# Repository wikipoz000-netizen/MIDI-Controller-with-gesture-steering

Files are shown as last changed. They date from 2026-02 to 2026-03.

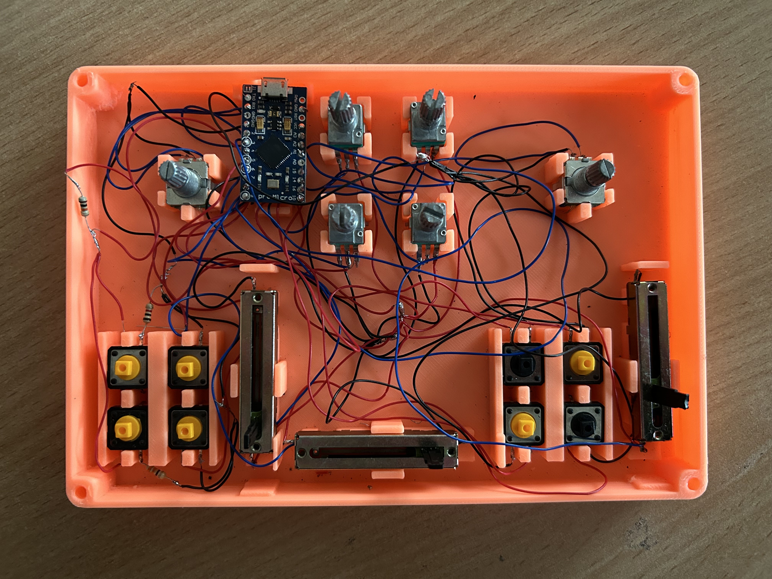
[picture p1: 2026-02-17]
pictures./budowa_DIY.jpg

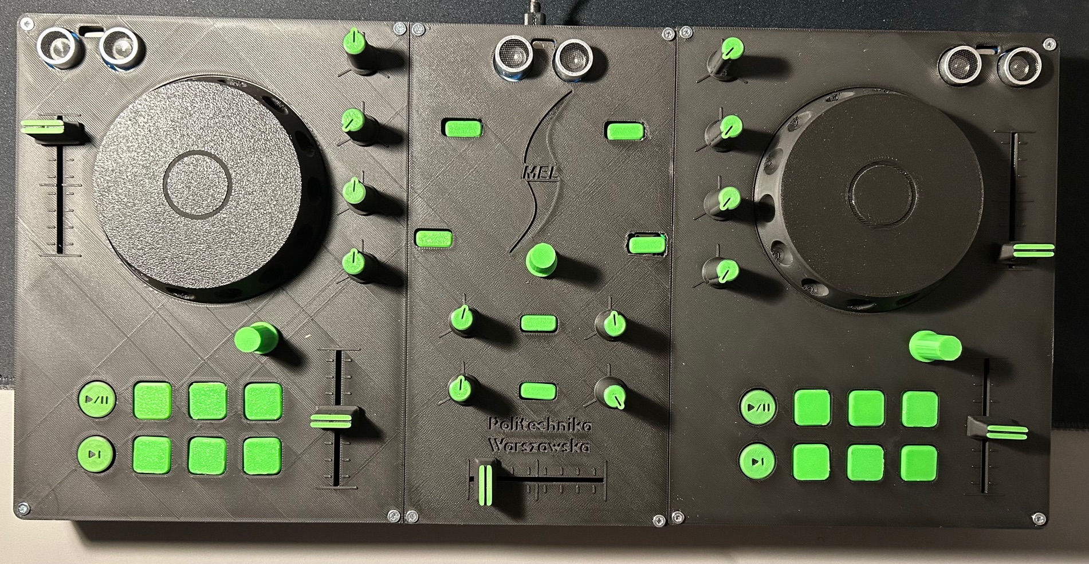
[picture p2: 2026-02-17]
pictures./final.jpeg

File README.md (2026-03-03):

English below
# MIDI DJ Controller z kontrolą gestami

Projekt przedstawia autorski kontroler MIDI DJ wzbogacony o eksperymentalny system sterowania gestami. Urządzenie zostało opracowane w ramach pracy inżynierskiej na kierunku **Automatyka i Robotyka**.

## Opis projektu

Urządzenie łączy tradycyjne elementy kontrolera DJ (fadery, pokrętła, koła jog, przyciski) z warstwą bezdotykowego sterowania gestami opartą na ultradźwiękowych czujnikach odległości.

Kontroler komunikuje się z komputerem poprzez interfejs **USB-MIDI** i jest w pełni kompatybilny z oprogramowaniem DJ-skim, takim jak **Mixxx**.

## Sprzęt (Hardware)

Główne komponenty systemu:

* **Mikrokontroler:** Raspberry Pi Pico (RP2040)
* **Wejścia analogowe:** Multiplekser ADC (rozszerzenie liczby kanałów analogowych)
* **Wejścia cyfrowe:** Ekspander GPIO (dodatkowe wejścia dla przycisków)
* **Detekcja gestów:** Ultradźwiękowe czujniki odległości
* **Interfejs dotykowy:** Pojemnościowe czujniki dotyku
* **Konstrukcja:** Dedykowana płytka PCB oraz obudowa wykonana w technologii druku 3D

Pełna dokumentacja sprzętowa, schematy oraz projekty PCB znajdują się w katalogu `/hardware`.

## Oprogramowanie układowe (Firmware)

Firmware odpowiada za:

* Odczyt i filtrowanie sygnałów z wejść analogowych i cyfrowych.
* Skalowanie sygnałów i eliminację szumów.
* Interpretację danych z czujników na konkretne gesty.
* Generowanie komunikatów MIDI (**Note On/Off, Control Change, Pitch Bend**).
* Komunikację USB-MIDI o niskim opóźnieniu.

Kod źródłowy dostępny jest w katalogu `/firmware`.

## Integracja z oprogramowaniem

Kontroler został przetestowany z oprogramowaniem **Mixxx**. W repozytorium znajdują się niezbędne pliki mapowania MIDI (formaty `.xml` oraz `.js`).

## Zawartość repozytorium

* **Hardware:** Schematy ideowe i projekty płytek drukowanych.
* **Firmware:** Kod źródłowy mikrokontrolera.
* **Mapping:** Pliki konfiguracyjne MIDI dla oprogramowania DJ.
* **Dokumentacja:** Wyniki testów i specyfikacja techniczna.

---

# MIDI DJ Controller with Gesture Control

This project presents a custom-built MIDI DJ controller enhanced with an experimental gesture control system.  
It was developed as part of an engineering thesis in Robotics and Automation.

## Project Description

The device combines traditional DJ controller elements (faders, knobs, jog wheels, buttons) with a contactless gesture control layer based on ultrasonic distance sensors.

The controller communicates with a computer via USB-MIDI and is compatible with DJ software such as Mixxx.

## Hardware

Main components:

- Raspberry Pi Pico (RP2040)
- ADC multiplexer (for extended analog inputs)
- GPIO expander (for additional digital inputs)
- Ultrasonic distance sensors (gesture detection)
- Capacitive touch sensing
- Custom-designed PCB
- 3D-printed enclosure

All hardware schematics and PCB files are available in the `/hardware` directory.

## Firmware

The firmware is responsible for:

- Reading analog and digital inputs
- Signal filtering and scaling
- Gesture interpretation
- Generating MIDI messages (Note On/Off, Control Change, Pitch Bend)
- USB-MIDI communication

Source code is available in the `/firmware` directory.

## Software Integration

The controller was tested with Mixxx DJ software.  
The repository includes MIDI mapping files (XML and JS).

## Repository Contents

- Hardware schematics
- PCB design files
- Firmware source code
- MIDI mapping configuration
- Documentation and test results

---
## Licencja

Ten projekt jest udostępniony na licencji **Creative Commons Zero**. 
Więcej informacji w pliku [LICENSE](LICENSE).

## Autor

Wiktor Pozarzycki  
Praca inżynierska – 2026

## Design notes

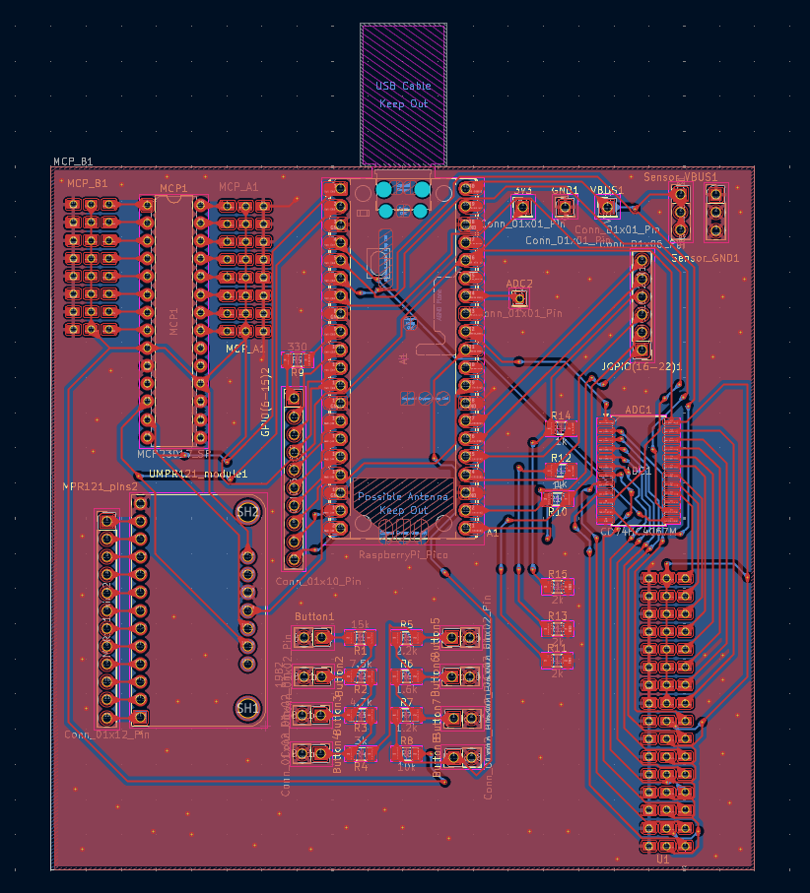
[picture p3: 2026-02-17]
pictures./PCB.png

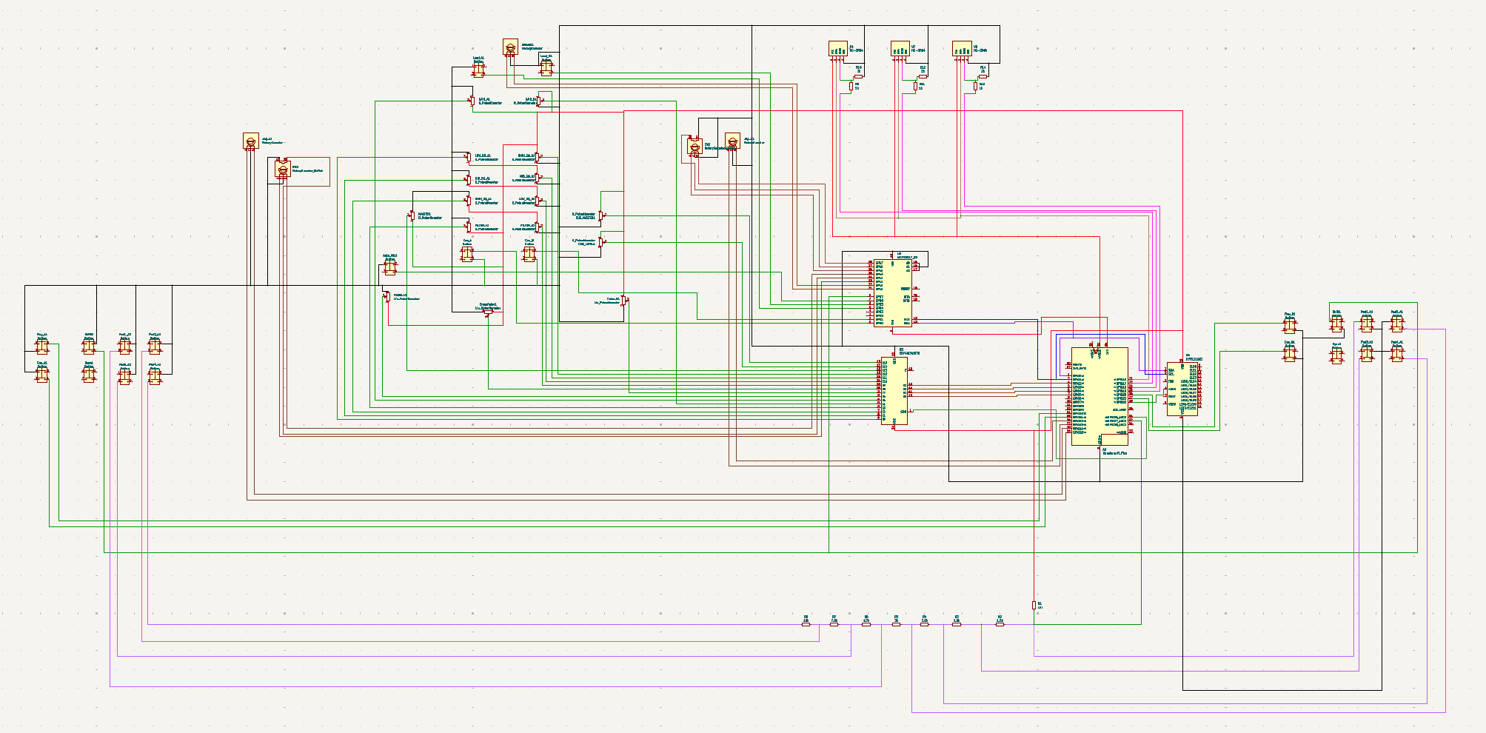
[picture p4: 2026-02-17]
pictures./caly_schemat.png

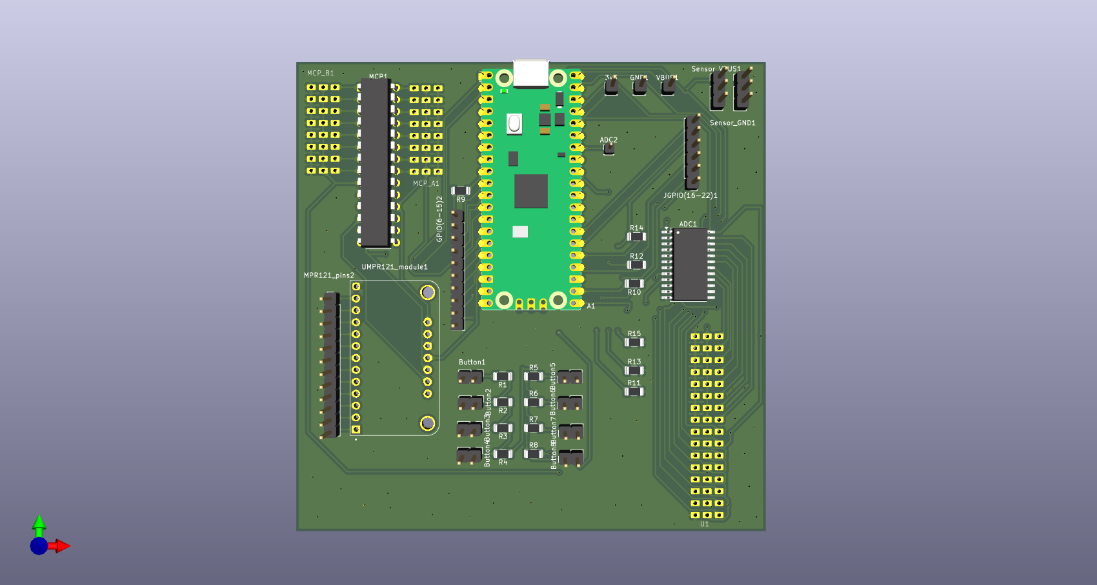
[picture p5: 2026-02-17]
pictures./Schemat_PCB.png

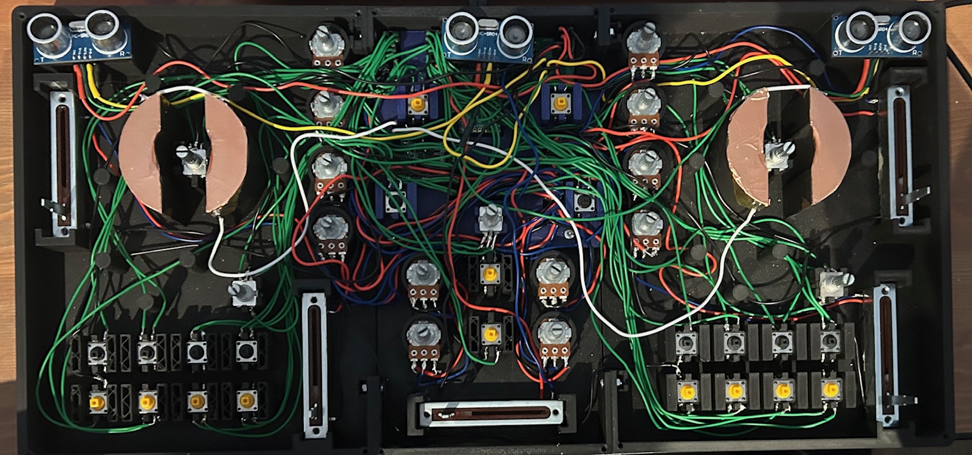
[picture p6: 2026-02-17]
pictures./urzadzenie.jpeg

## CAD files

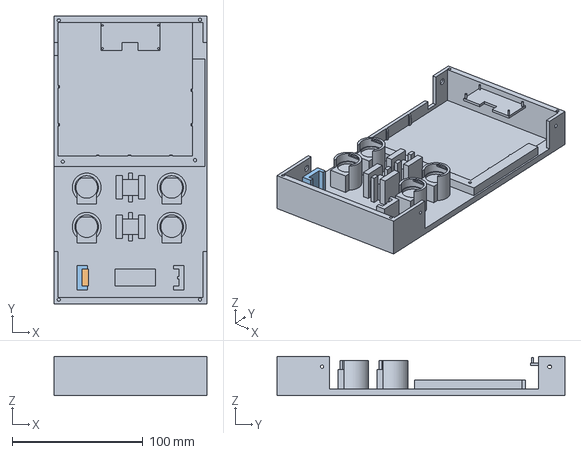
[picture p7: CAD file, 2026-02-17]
3D models/Obudowa_S.step
117.0 x 220.0 x 30.0 mm

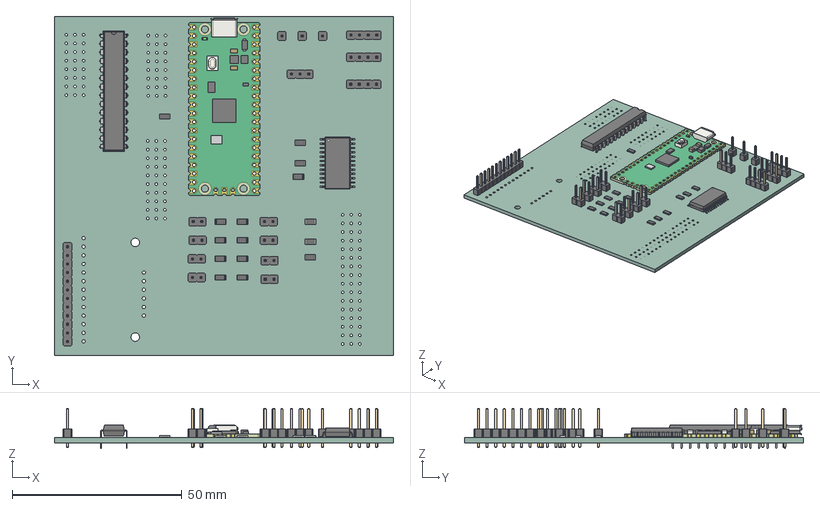
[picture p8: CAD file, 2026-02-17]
schemes/Schemat_PCB/Schemat_PCB.step
100.0 x 100.0 x 11.8 mm
DIP-28_W7.62mm
R_1206_3216Metric x 15
SOIC-24W_7.5x15.4mm_P1.27mm
RaspberryPi_Pico_Module_KiCad
PinHeader_1x02_P2.54mm_Vertical x 8
PinHeader_1x01_P2.54mm_Vertical x 3
PinHeader_1x04_P2.54mm_Vertical x 3
PinHeader_1x12_P2.54mm_Vertical
PinHeader_1x03_P2.54mm_Vertical
Schemat_PCB_PCB

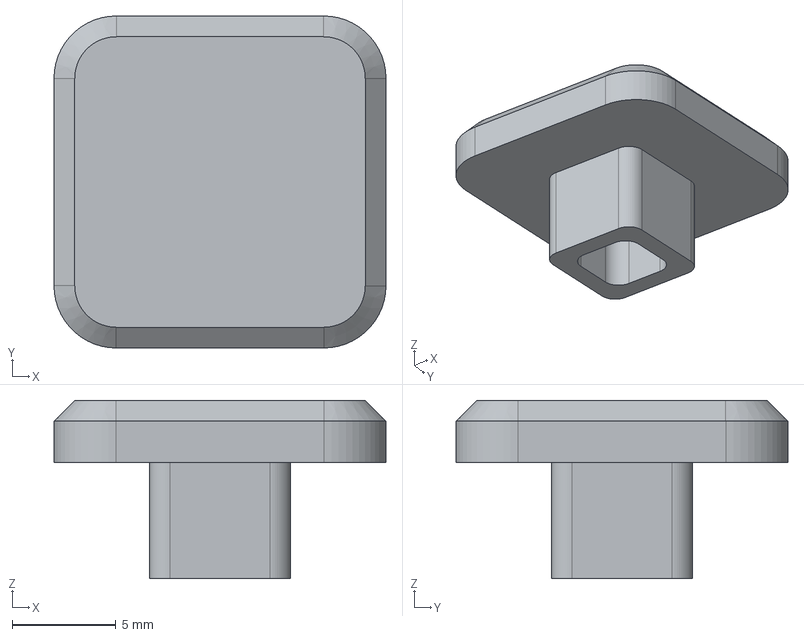
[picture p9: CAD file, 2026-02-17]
3D models/Przycisk_Duzy.step
16.0 x 16.0 x 8.60 mm

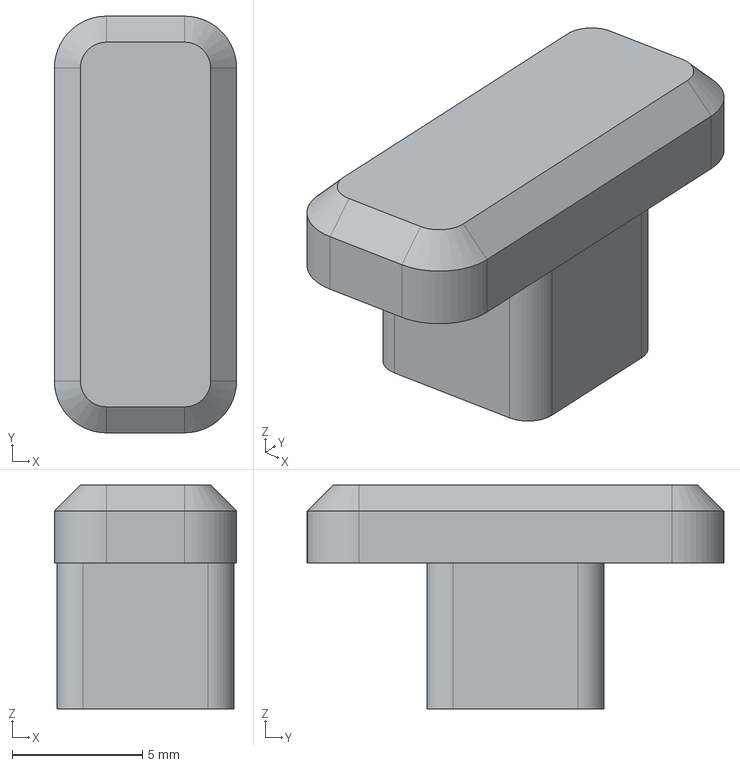
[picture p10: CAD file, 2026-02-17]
3D models/Przycisk_Maly.step
7.00 x 16.0 x 8.60 mm

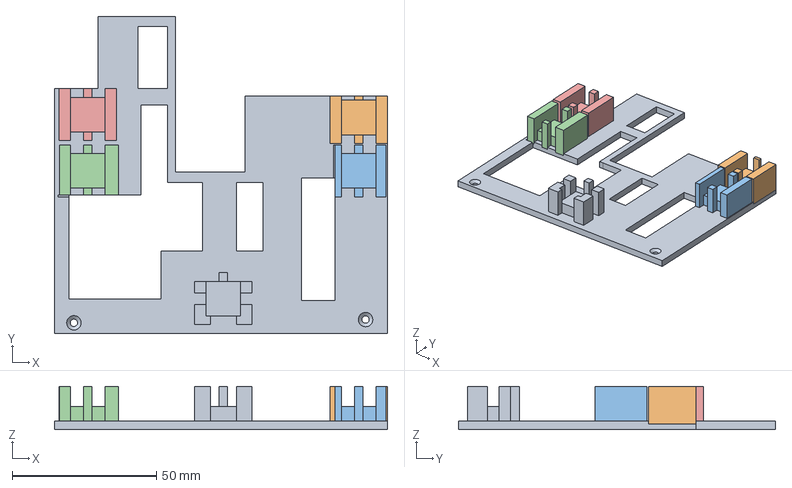
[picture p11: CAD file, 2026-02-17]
3D models/Nakladka2.step
115.5 x 110.0 x 15.0 mm

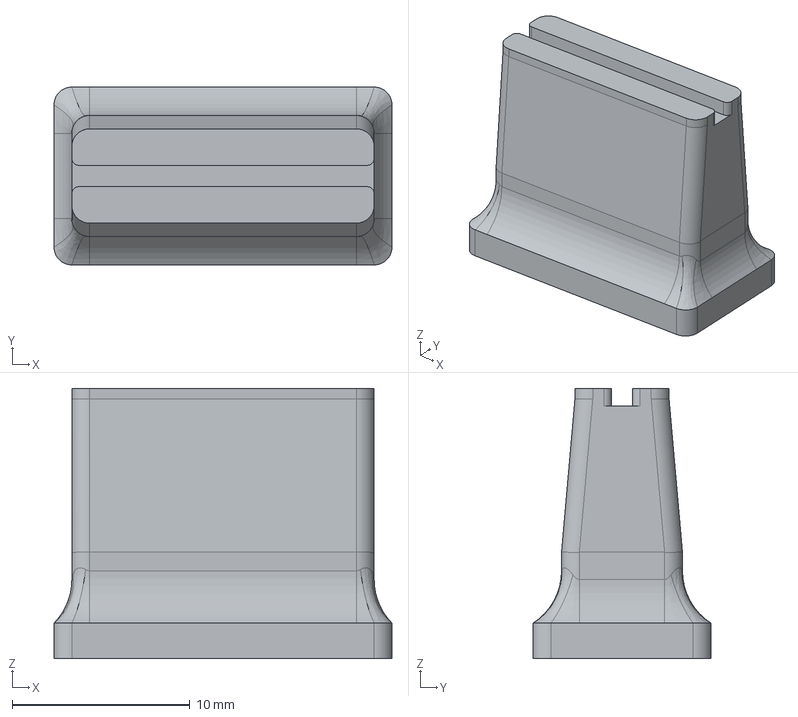
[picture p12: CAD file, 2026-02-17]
3D models/tempo-fader-Body.step
19.0 x 10.0 x 15.2 mm

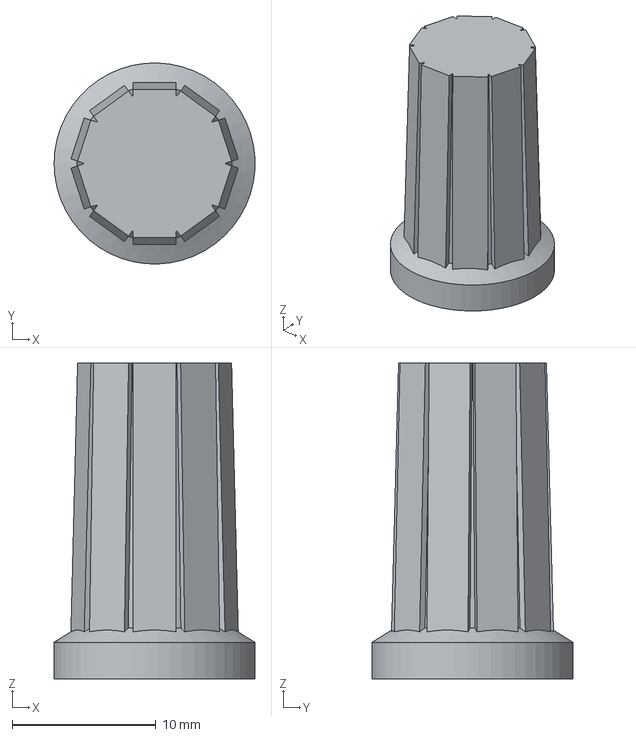
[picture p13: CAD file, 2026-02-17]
3D models/Pokretlo1.step
14.0 x 14.0 x 22.0 mm

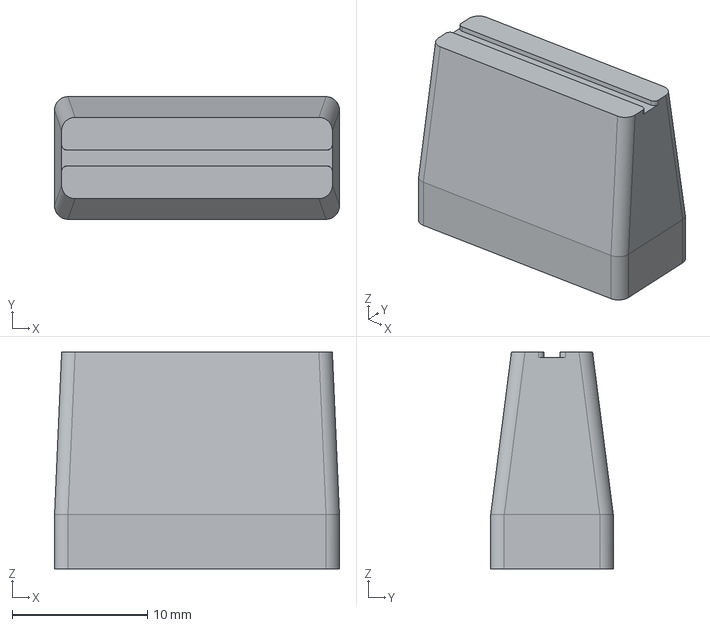
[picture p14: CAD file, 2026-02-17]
3D models/crossfader-BodyFillet.step
21.0 x 9.06 x 16.0 mm

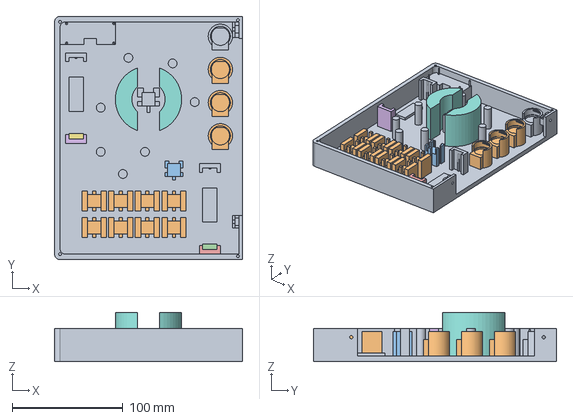
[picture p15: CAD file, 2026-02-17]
3D models/Obudowa_L.step
170.0 x 220.0 x 44.5 mm

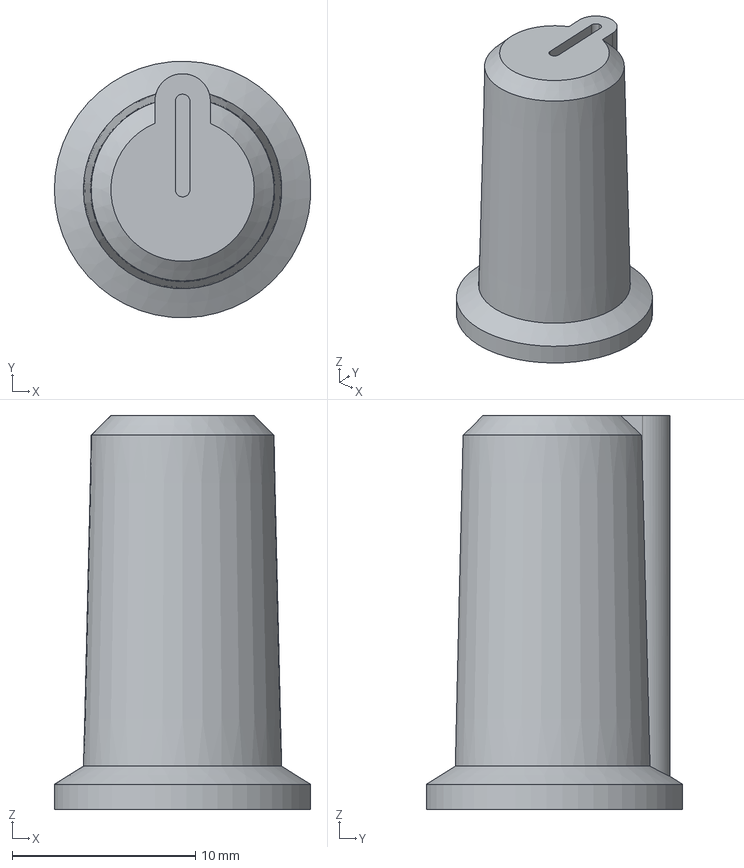
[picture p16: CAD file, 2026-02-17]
3D models/Pokretlo2.step
14.0 x 14.0 x 21.5 mm

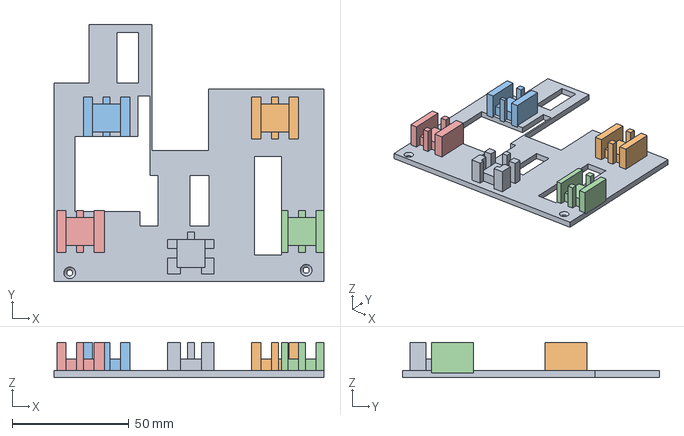
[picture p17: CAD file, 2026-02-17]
3D models/Nakladka.step
115.5 x 110.0 x 15.0 mm

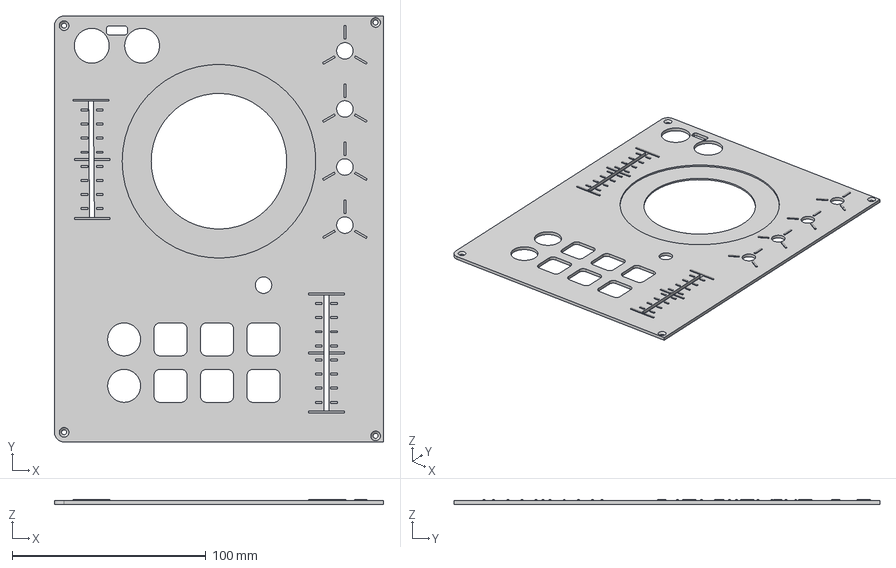
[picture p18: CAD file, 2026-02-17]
3D models/Gora_L.step
170.0 x 220.0 x 2.50 mm

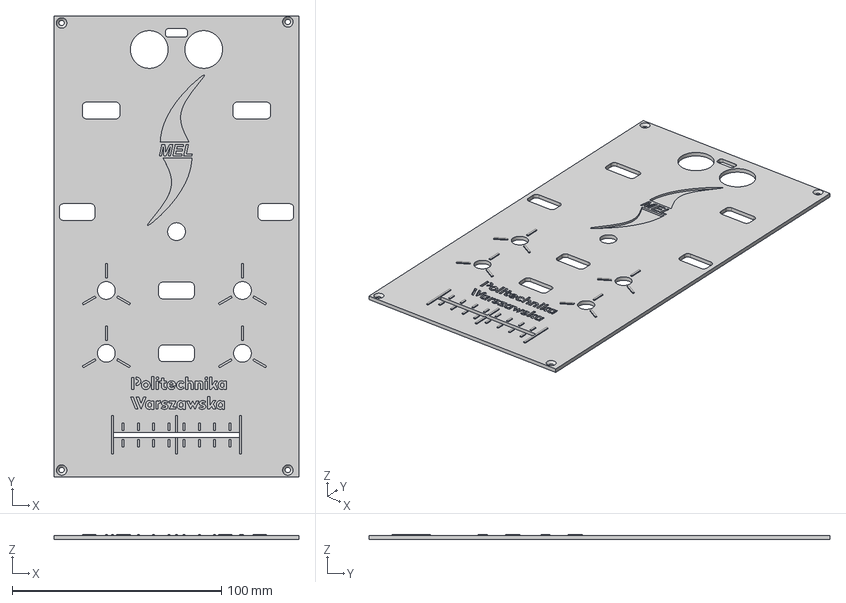
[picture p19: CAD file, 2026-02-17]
3D models/Gora_S.step
117.0 x 220.0 x 2.50 mm

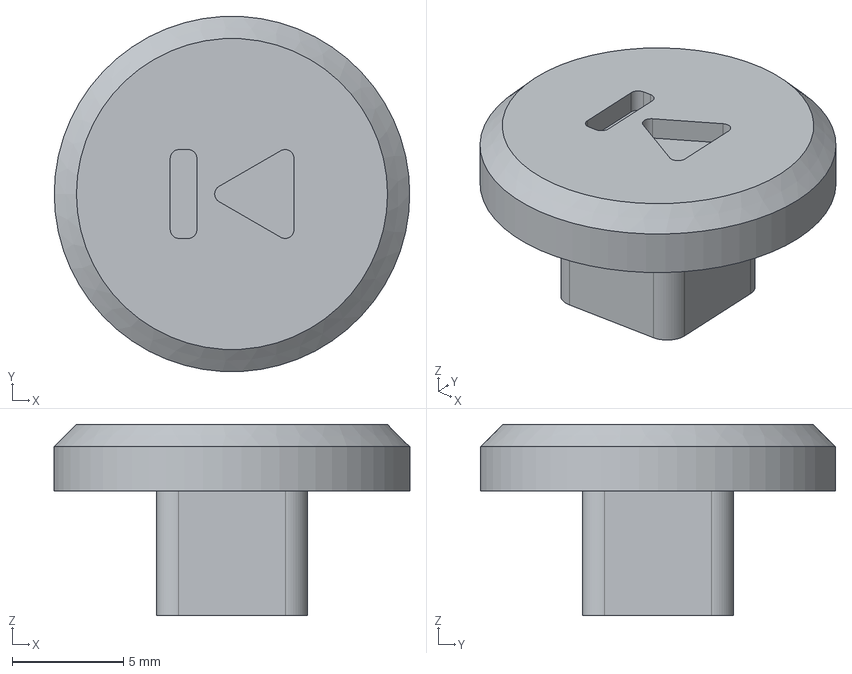
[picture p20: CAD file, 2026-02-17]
3D models/cue-Body.step
16.0 x 16.0 x 8.60 mm

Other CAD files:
3D models/Gora_P.step
3D models/Jog.step
3D models/play-pause-Body.step
3D models/Obudowa_P.step

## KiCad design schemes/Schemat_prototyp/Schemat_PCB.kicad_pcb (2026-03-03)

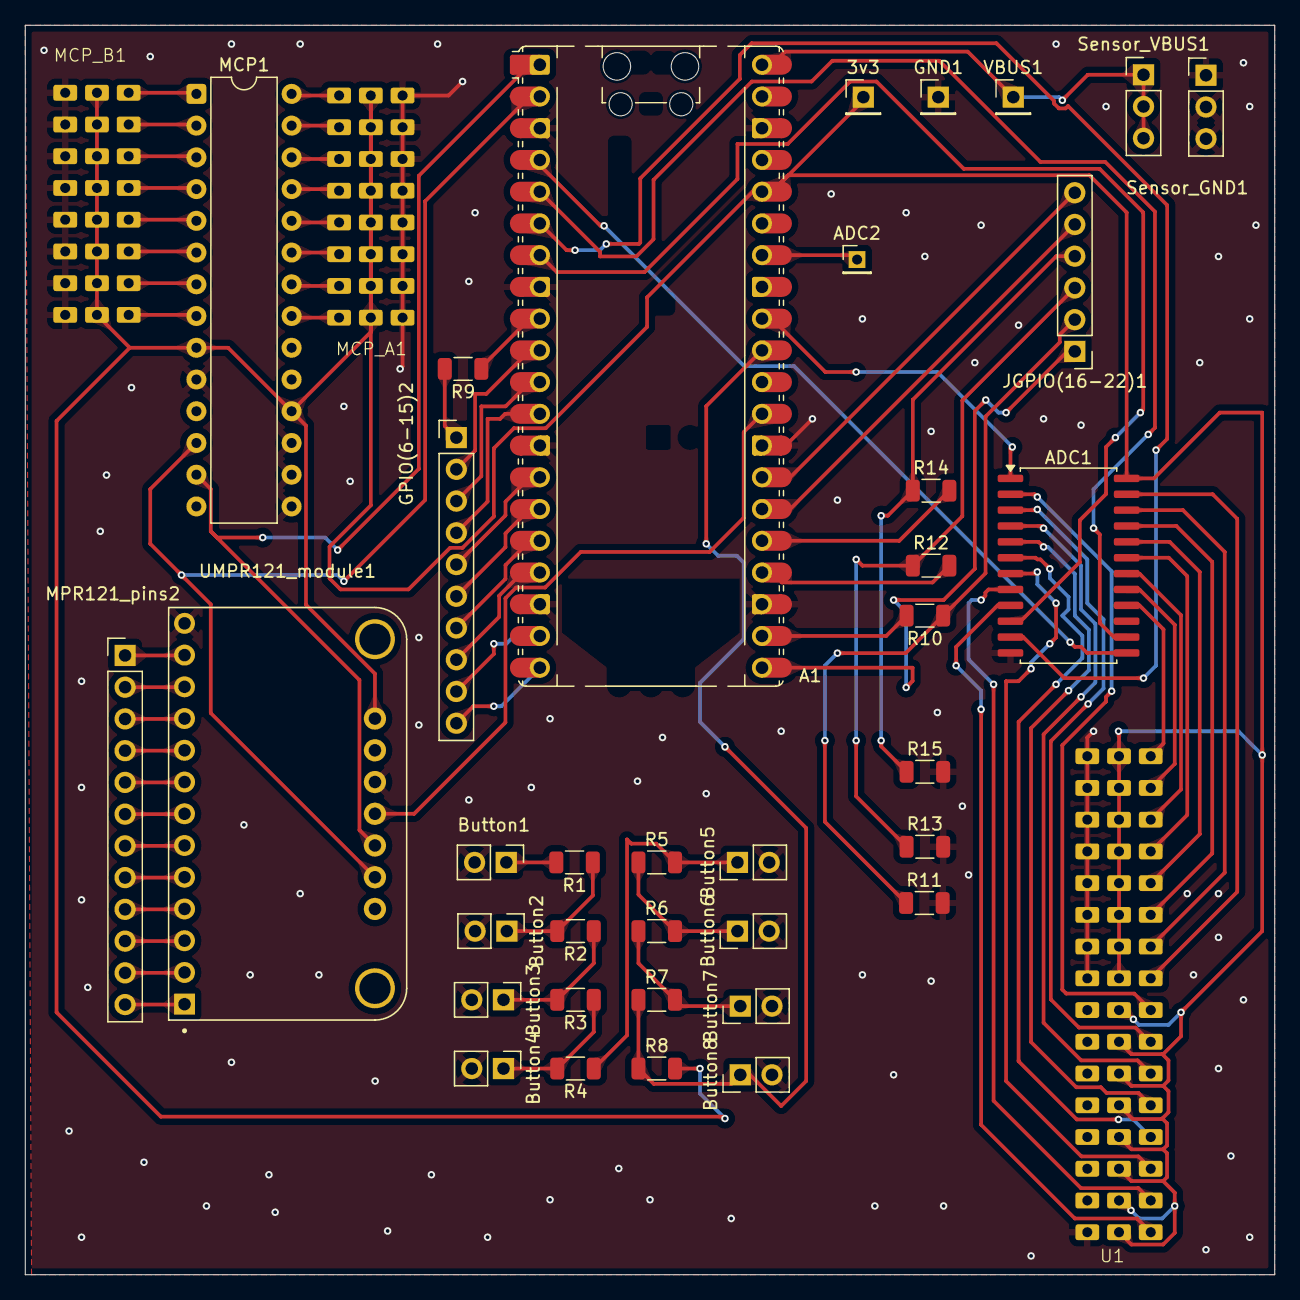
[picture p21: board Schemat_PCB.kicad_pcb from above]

Board: 2 copper layers, 100.0 x 100.0 mm, 39 parts (0 on the bottom side), 84 nets.

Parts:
3v3: Conn_01x01_Pin; PinHeader_1x01_P2.54mm_Vertical
A1: RaspberryPi_Pico; RaspberryPi_Pico_Common_Unspecified
ADC1: CD74HC4067M; SOIC-24W_7.5x15.4mm_P1.27mm
ADC2: Conn_01x01_Pin; PinHeader_1x01_P2.00mm_Vertical
Button1, Button2, Button3, Button4, Button5, Button6, Button7, Button8: Conn_01x02_Pin; PinHeader_1x02_P2.54mm_Vertical
GND1: Conn_01x01_Pin; PinHeader_1x01_P2.54mm_Vertical
GPIO(6-15)2: Conn_01x10_Pin; PinHeader_1x10_P2.54mm_Vertical
JGPIO(16-22)1: Conn_01x06_Pin; PinHeader_1x06_P2.54mm_Vertical
MCP1: MCP23017_SP; DIP-28_W7.62mm
MCP_A1: PinHeader_3x8_2.54mm_MIRROR
MCP_B1: PinHeader_3x8_2.54mm_MIRROR
MPR121_pins2: Conn_01x12_Pin; PinHeader_1x12_P2.54mm_Vertical
R1: 15k; R_1206_3216Metric
R2: 7.5k; R_1206_3216Metric
R3: 4.7k; R_1206_3216Metric
R4: 3k; R_1206_3216Metric
R5: 2.2k; R_1206_3216Metric
R6: 1.6k; R_1206_3216Metric
R7: 1.2k; R_1206_3216Metric
R8: 10k; R_1206_3216Metric
R9: 330; R_1206_3216Metric
R10, R12, R14: 1k; R_1206_3216Metric
R11, R13, R15: 2k; R_1206_3216Metric
Sensor_GND1: Conn_01x03_Pin; PinHeader_1x03_P2.54mm_Vertical
Sensor_VBUS1: Conn_01x03_Pin; PinHeader_1x03_P2.54mm_Vertical
U1: PinHeader_3x16_2.54mm
UMPR121_module1: 1982; MODULE_1982
VBUS1: Conn_01x01_Pin; PinHeader_1x01_P2.54mm_Vertical

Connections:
GND: A1.3 (GND), A1.8 (GND), A1.13 (GND), A1.18 (GND), A1.23 (GND), A1.28 (GND), A1.38 (GND), ADC1.12 (GND), Button1.2, Button2.2, Button3.2, Button4.2, Button5.2, Button6.2, Button7.2, Button8.2, GND1.1, MCP1.10 (VSS), MCP1.15 (A0), MCP1.16 (A1), MCP1.17 (A2), MCP_A1.17 (GND), MCP_A1.18 (GND), MCP_A1.19 (GND), MCP_A1.20 (GND), MCP_A1.21 (GND), MCP_A1.22 (GND), MCP_A1.23 (GND), MCP_A1.24 (GND), MCP_B1.17 (GND), MCP_B1.18 (GND), MCP_B1.19 (GND), MCP_B1.20 (GND), MCP_B1.21 (GND), MCP_B1.22 (GND), MCP_B1.23 (GND), MCP_B1.24 (GND), R11.2, R13.2, R15.2, Sensor_GND1.1, Sensor_GND1.2, Sensor_GND1.3, U1.33 (GND), U1.34 (GND), U1.35 (GND), U1.36 (GND), U1.37 (GND), U1.38 (GND), U1.39 (GND), U1.40 (GND), U1.41 (GND), U1.42 (GND), U1.43 (GND), U1.44 (GND), U1.45 (GND), U1.46 (GND), U1.47 (GND), U1.48 (GND), UMPR121_module1.JP1_13 (GND), UMPR121_module1.JP2_3 (GND)
unnamed: 3v3.1, A1.36 (3V3), ADC1.24 (VCC), MCP1.9 (VDD), MCP1.18 (~RESET), MCP_A1.9 (VCC), MCP_A1.10 (VCC), MCP_A1.11 (VCC), MCP_A1.12 (VCC), MCP_A1.13 (VCC), MCP_A1.14 (VCC), MCP_A1.15 (VCC), MCP_A1.16 (VCC), MCP_B1.9 (VCC), MCP_B1.10 (VCC), MCP_B1.11 (VCC), MCP_B1.12 (VCC), MCP_B1.13 (VCC), MCP_B1.14 (VCC), MCP_B1.15 (VCC), MCP_B1.16 (VCC), R8.2, U1.17 (VCC), U1.18 (VCC), U1.19 (VCC), U1.20 (VCC), U1.21 (VCC), U1.22 (VCC), U1.23 (VCC), U1.24 (VCC), U1.25 (VCC), U1.26 (VCC), U1.27 (VCC), U1.28 (VCC), U1.29 (VCC), U1.30 (VCC), U1.31 (VCC), U1.32 (VCC), UMPR121_module1.JP2_1 (VIN)
unnamed: A1.1 (GPIO0), MCP1.13 (SDA), UMPR121_module1.JP2_5 (SDA)
unnamed: A1.2 (GPIO1), MCP1.12 (SCK), UMPR121_module1.JP2_6 (SCL)
unnamed: A1.4 (GPIO2), ADC1.13 (S3)
unnamed: A1.5 (GPIO3), ADC1.14 (S2)
unnamed: A1.6 (GPIO4), ADC1.11 (S1)
unnamed: A1.7 (GPIO5), ADC1.10 (S0)
unnamed: A1.9 (GPIO6), R9.1
unnamed: A1.10 (GPIO7), GPIO(6-15)2.2
unnamed: A1.11 (GPIO8), GPIO(6-15)2.3
unnamed: A1.12 (GPIO9), GPIO(6-15)2.4
unnamed: A1.14 (GPIO10), GPIO(6-15)2.5
unnamed: A1.15 (GPIO11), GPIO(6-15)2.6
unnamed: A1.16 (GPIO12), GPIO(6-15)2.7
unnamed: A1.17 (GPIO13), GPIO(6-15)2.8
unnamed: A1.19 (GPIO14), GPIO(6-15)2.9
unnamed: A1.20 (GPIO15), GPIO(6-15)2.10
unnamed: A1.21 (GPIO16), JGPIO(16-22)1.1
unnamed: A1.22 (GPIO17), R10.2
unnamed: A1.24 (GPIO18), R12.2
unnamed: A1.25 (GPIO19), R14.2
unnamed: A1.26 (GPIO20), JGPIO(16-22)1.5
unnamed: A1.27 (GPIO21), JGPIO(16-22)1.6
unnamed: A1.29 (GPIO22), UMPR121_module1.JP2_4 (ADDR)
unnamed: A1.31 (GPIO26_ADC0), Button8.1, R7.1, R8.1
unnamed: A1.32 (GPIO27_ADC1), ADC1.1 (COM)
unnamed: A1.34 (GPIO28_ADC2), ADC2.1
unnamed: A1.40 (VBUS), Sensor_VBUS1.1, Sensor_VBUS1.2, Sensor_VBUS1.3, VBUS1.1
unnamed: ADC1.9 (I0), U1.1 (A1)
unnamed: ADC1.8 (I1), U1.2 (A2)
unnamed: ADC1.7 (I2), U1.3 (A3)
unnamed: ADC1.6 (I3), U1.4 (A4)
unnamed: ADC1.5 (I4), U1.5 (A5)
unnamed: ADC1.4 (I5), U1.6 (A6)
unnamed: ADC1.3 (I6), U1.7 (A7)
unnamed: ADC1.2 (I7), U1.8 (A8)
unnamed: ADC1.23 (I8), U1.9 (A9)
unnamed: ADC1.22 (I9), U1.10 (A10)
unnamed: ADC1.21 (I10), U1.11 (A11)
unnamed: ADC1.20 (I11), U1.12 (A12)
unnamed: ADC1.19 (I12), U1.13 (A13)
unnamed: ADC1.18 (I13), U1.14 (A14)
unnamed: ADC1.17 (I14), U1.15 (A15)
unnamed: ADC1.16 (I15), U1.16 (A16)
unnamed: Button1.1, R1.2
unnamed: Button2.1, R1.1, R2.2
unnamed: Button3.1, R2.1, R3.2
unnamed: Button4.1, R3.1, R4.2
unnamed: Button5.1, R4.1, R5.2
unnamed: Button6.1, R5.1, R6.2
unnamed: Button7.1, R6.1, R7.2
unnamed: GPIO(6-15)2.1, R9.2
unnamed: JGPIO(16-22)1.2, R10.1, R11.1
unnamed: JGPIO(16-22)1.3, R12.1, R13.1
unnamed: JGPIO(16-22)1.4, R14.1, R15.1
unnamed: MCP1.21 (GPA0), MCP_A1.1 (A1)
unnamed: MCP1.22 (GPA1), MCP_A1.2 (A2)
unnamed: MCP1.23 (GPA2), MCP_A1.3 (A3)
unnamed: MCP1.24 (GPA3), MCP_A1.4 (A4)
unnamed: MCP1.25 (GPA4), MCP_A1.5 (A5)
unnamed: MCP1.26 (GPA5), MCP_A1.6 (A6)
unnamed: MCP1.27 (GPA6), MCP_A1.7 (A7)
unnamed: MCP1.28 (GPA7), MCP_A1.8 (A8)
unnamed: MCP1.1 (GPB0), MCP_B1.1 (A1)
unnamed: MCP1.2 (GPB1), MCP_B1.2 (A2)
unnamed: MCP1.3 (GPB2), MCP_B1.3 (A3)
unnamed: MCP1.4 (GPB3), MCP_B1.4 (A4)
unnamed: MCP1.5 (GPB4), MCP_B1.5 (A5)
unnamed: MCP1.6 (GPB5), MCP_B1.6 (A6)
unnamed: MCP1.7 (GPB6), MCP_B1.7 (A7)
unnamed: MCP1.8 (GPB7), MCP_B1.8 (A8)
unnamed: MPR121_pins2.1, UMPR121_module1.JP1_12 (ELEC0)
unnamed: MPR121_pins2.2, UMPR121_module1.JP1_11 (ELEC1)
unnamed: MPR121_pins2.3, UMPR121_module1.JP1_10 (ELEC2)
unnamed: MPR121_pins2.4, UMPR121_module1.JP1_9 (ELEC3)
unnamed: MPR121_pins2.5, UMPR121_module1.JP1_8 (ELEC4)
unnamed: MPR121_pins2.6, UMPR121_module1.JP1_7 (ELEC5)
unnamed: MPR121_pins2.7, UMPR121_module1.JP1_6 (ELEC6)
unnamed: MPR121_pins2.8, UMPR121_module1.JP1_5 (ELEC7)
unnamed: MPR121_pins2.9, UMPR121_module1.JP1_4 (ELEC8)
unnamed: MPR121_pins2.10, UMPR121_module1.JP1_3 (ELEC9)
unnamed: MPR121_pins2.11, UMPR121_module1.JP1_2 (ELEC10)
unnamed: MPR121_pins2.12, UMPR121_module1.JP1_1 (ELEC11)

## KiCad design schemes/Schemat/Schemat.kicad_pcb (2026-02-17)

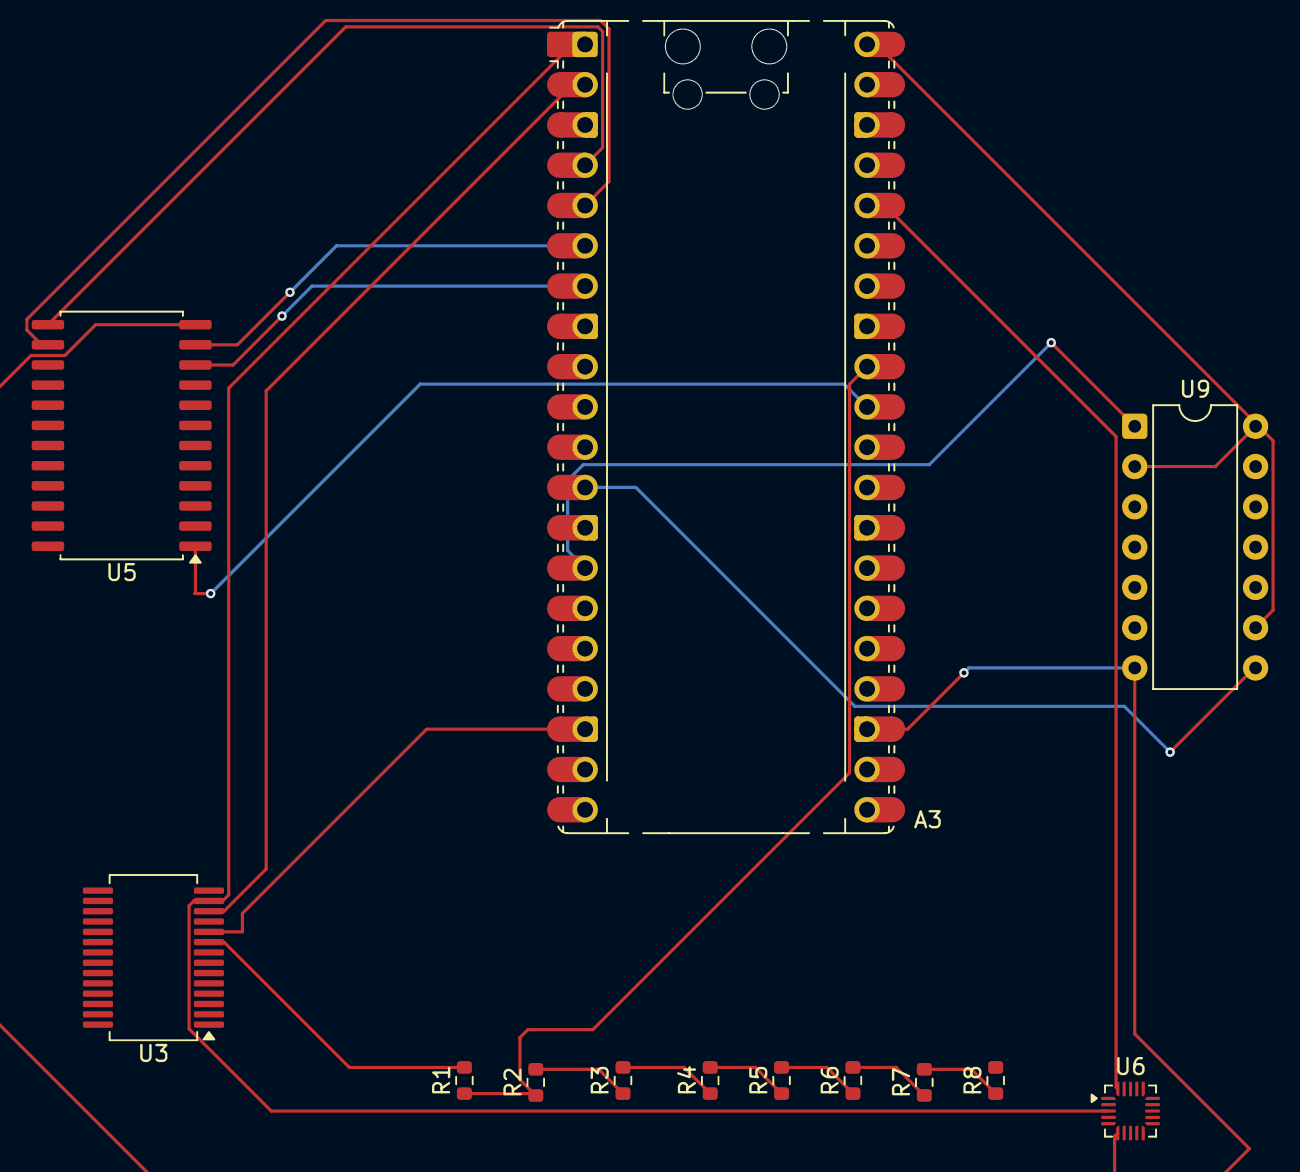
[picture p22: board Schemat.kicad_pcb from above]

Board: 2 copper layers, 13 parts (0 on the bottom side), 19 nets.

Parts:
A3: RaspberryPi_Pico; RaspberryPi_Pico_Common_Unspecified
R1: 10k; R_0603_1608Metric
R2: 1.2k; R_0603_1608Metric
R3: 1.6k; R_0603_1608Metric
R4: 2.2k; R_0603_1608Metric
R5: 3k; R_0603_1608Metric
R6: 4.7k; R_0603_1608Metric
R7: 7.5k; R_0603_1608Metric
R8: 15k; R_0603_1608Metric
U3: MCP23017_SS; SSOP-28_5.3x10.2mm_P0.65mm
U5: CD74HC4067M; SOIC-24W_7.5x15.4mm_P1.27mm
U6: MPR121QR2; UQFN-20_3x3mm_P0.4mm
U9: 74HCT164; DIP-14_W7.62mm

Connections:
unnamed: A3.36 (3V3), R1.2, U3.9 (VDD), U5.24 (VCC), U6.20 (VDD)
unnamed: A3.1 (GPIO0), U3.13 (SDA), U6.3 (SDA)
unnamed: A3.2 (GPIO1), U3.12 (SCK), U6.2 (SCL)
unnamed: A3.4 (GPIO2), U5.13 (S3)
unnamed: A3.5 (GPIO3), U5.14 (S2)
unnamed: A3.6 (GPIO4), U5.11 (S1)
unnamed: A3.7 (GPIO5), U5.10 (S0)
unnamed: A3.12 (GPIO9), U9.8 (CP)
unnamed: A3.14 (GPIO10), U9.1 (DSA)
unnamed: A3.31 (GPIO26_ADC0), U5.1 (COM)
unnamed: A3.32 (GPIO27_ADC1), R1.1, R2.1
unnamed: A3.40 (VBUS), U9.2 (DSB), U9.9 (~MR), U9.14 (VCC)
unnamed: R2.2, R3.1
unnamed: R3.2, R4.1
unnamed: R4.2, R5.1
unnamed: R5.2, R6.1
unnamed: R6.2, R7.1
unnamed: R7.2, R8.1
unnamed: A3.3 (GND), A3.8 (GND), A3.13 (GND), A3.18 (GND), A3.23 (GND), A3.28 (GND), A3.38 (GND), U3.10 (VSS), U5.12 (GND), U6.6 (VSS), U9.7 (GND)

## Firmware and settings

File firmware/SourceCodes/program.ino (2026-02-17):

#include "Config.h"
#include "State.h"
#include "MIDI.h"
#include "MCP.h"
#include "GPIO_Input.h"
#include "ADC_Input.h"
#include "Pads.h"
#include "MPR121_Touch.h"
#include "Gestures.h"
#include "Debug.h"
#include <Wire.h>

void setup() {
  Wire.setSDA(SDA_PIN);
  Wire.setSCL(SCL_PIN);
  Wire.begin();

  initMIDI();
  initMCP();
  initGPIO();
  initADC();
  initPads();
  initMPR121();
  initGestures();
  initDebug();
}

void loop() {
  updateMCP();
  updateMPR121();
  updateGPIO();      // enkodery GPIO
  updateADC();
  updatePads();
  updateDebug();
  updateGestures();  // gesty NA KOŃCU
  delay(1);
}

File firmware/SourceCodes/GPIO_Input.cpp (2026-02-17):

#include "GPIO_Input.h"
#include "Config.h"
#include "MIDI.h"
#include "MPR121_Touch.h"
#include <Arduino.h>

/* =====================================================
   ================= ENCODER GRAY TABLE ================
   ===================================================== */

static const int8_t ENC_TABLE[16] = {
   0, -1,  1,  0,
   1,  0,  0, -1,
  -1,  0,  0,  1,
   0,  1, -1,  0
};

/* =====================================================
   ================= ENCODER STRUCT ====================
   ===================================================== */

struct Encoder {
  uint8_t pinA;
  uint8_t pinB;
  uint8_t lastState;
  int8_t  step;      // akumulacja kroków
};

/* =====================================================
   ================= ENCODERS ==========================
   ===================================================== */

static Encoder jogA = {
  JOG_A_A,
  JOG_A_B,
  0,
  0
};

static Encoder jogB = {
  JOG_B_A,
  JOG_B_B,
  0,
  0
};

static Encoder browse = {
  BROWSE_A,
  BROWSE_B,
  0,
  0
};
// ===== DEBUG MIRRORS =====
int8_t jogStepA = 0;
int8_t jogStepB = 0;
int8_t browseStep = 0;
static int8_t  browseAccum = 0;
static uint32_t browseLastMove = 0;

/* =====================================================
   ================= BUTTON STRUCT =====================
   ===================================================== */

struct Button {
  uint8_t pin;
  bool state;
  bool last;
  uint32_t lastTime;
};

static Button buttons[] = {
  { PLAY_A_PIN, false, false, 0 },
  { CUE_A_PIN,  false, false, 0 },
  { PLAY_B_PIN, false, false, 0 },
  { CUE_B_PIN,  false, false, 0 }
};

constexpr uint8_t BTN_COUNT = sizeof(buttons) / sizeof(Button);

/* =====================================================
   ================= INIT ==============================
   ===================================================== */

void initGPIO() {

  // --- ENCODERS ---
  pinMode(JOG_A_A, INPUT_PULLUP);
  pinMode(JOG_A_B, INPUT_PULLUP);
  pinMode(JOG_B_A, INPUT_PULLUP);
  pinMode(JOG_B_B, INPUT_PULLUP);
  pinMode(BROWSE_A, INPUT_PULLUP);
  pinMode(BROWSE_B, INPUT_PULLUP);

  jogA.lastState =
    (digitalRead(jogA.pinA) << 1) | digitalRead(jogA.pinB);
  jogB.lastState =
    (digitalRead(jogB.pinA) << 1) | digitalRead(jogB.pinB);
  browse.lastState =
    (digitalRead(browse.pinA) << 1) | digitalRead(browse.pinB);

  // --- BUTTONS ---
  pinMode(PLAY_A_PIN, INPUT_PULLUP);
  pinMode(CUE_A_PIN,  INPUT_PULLUP);
  pinMode(PLAY_B_PIN, INPUT_PULLUP);
  pinMode(CUE_B_PIN,  INPUT_PULLUP);
}

/* =====================================================
   ================= ENCODER READ ======================
   ===================================================== */

static inline int8_t readEncoder(Encoder &e) {

  uint8_t s =
    (digitalRead(e.pinA) << 1) |
     digitalRead(e.pinB);

  uint8_t idx = (e.lastState << 2) | s;
  int8_t delta = ENC_TABLE[idx];

  e.lastState = s;
  return delta;
}

/* =====================================================
   ================= SEND RELATIVE CC ==================
   ===================================================== */

static inline void sendRelativeCC(uint8_t ch, uint8_t cc, int8_t step) {
  if (step == 0) return;

  uint8_t val = (step > 0) ? 65 : 63;
  sendCC(ch, cc, val);
}

/* =====================================================
   ================= UPDATE ============================
   ===================================================== */

void updateGPIO() {

  /* ---------- ENCODERS ---------- */

  jogA.step   += readEncoder(jogA);
  jogB.step   += readEncoder(jogB);
  browse.step += readEncoder(browse);

// --- JOG A ---
if (jogA.step != 0) {
  if (isJogTouchedA())
    sendPitchBend(MIDI_CH_A, jogA.step * 256);
  else
    sendRelativeCC(MIDI_CH_A, 42, jogA.step);

  jogStepA = jogA.step;
  jogA.step = 0;
}

// --- JOG B ---
if (jogB.step != 0) {
  if (isJogTouchedB())
    sendPitchBend(MIDI_CH_B, jogB.step * 256);
  else
    sendRelativeCC(MIDI_CH_B, 74, jogB.step);

  jogStepB = jogB.step;
  jogB.step = 0;
}

// --- BROWSE (gesture-based) ---

// akumuluj kroki
if (browse.step != 0) {
  browseAccum += browse.step;
  browseLastMove = millis();
  browse.step = 0;
}
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

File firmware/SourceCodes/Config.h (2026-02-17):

#pragma once
#include <Arduino.h>

// ===== I2C (RP2040 / Pico) =====
#define SDA_PIN 0
#define SCL_PIN 1

// ===== MIDI CHANNELS =====
#define MIDI_CH_A 1
#define MIDI_CH_B 2

// ===== DECKI =====
enum Deck {
  DECK_A = 0,
  DECK_B = 1
};

// ===== TRYBY GESTÓW (JEDYNA DEFINICJA) =====
enum GestureMode {
  MODE_EQ = 0,
  MODE_FX,
  MODE_DYNAMICS,
  MODE_MACRO,
  MODE_NONE
};


// ===== TYPY GESTÓW =====
enum GestureType {
  G_UPDOWN = 0,   // ciągły CC (góra/dół)
  G_TAP,          // szybkie machnięcie nad jednym czujnikiem
  G_SWIPE_L,      // globalny swipe right -> left
  G_SWIPE_R,      // globalny swipe left -> right
  G_HAND_ON,      // ręka pojawia się nad czujnikiem
  G_HAND_OFF      // ręka znika
};


// ===== TYP MIDI =====
enum MidiType {
  MIDI_CC = 0,
  MIDI_NOTE
};

// ===== PERFORMANCE PADS (ADC) =====
#define PAD_TOL 40
#define PAD_A1 790
#define PAD_A2 680
#define PAD_A3 570
#define PAD_A4 450
#define PAD_B1 333
#define PAD_B2 212
#define PAD_B3 104
#define PAD_B4 2

// ===== GPIO ENCODERS =====
#define JOG_A_A     15
#define JOG_A_B     14

#define JOG_B_A     11
#define JOG_B_B     10

#define BROWSE_A    7
#define BROWSE_B    6

// ===== GPIO BUTTONS =====
#define PLAY_A_PIN  12
#define CUE_A_PIN   13

#define PLAY_B_PIN  9
#define CUE_B_PIN   8
